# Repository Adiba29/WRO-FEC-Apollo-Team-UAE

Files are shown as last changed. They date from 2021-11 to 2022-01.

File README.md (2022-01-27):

# Engineering Materials

This repository contains engineering materials for **UAE's Team Apollo** participating  in in the WRO Future Engineers competition International Finals in the season 2021.

## Content

* `photos` contains 6 photos of the vehicle (from every side, from top and bottom)
* `schemes` contains one or several schematic diagrams in form of JPEG, PNG or PDF of the electromechanical components illustrating all the elements (electronic components and motors) used in the vehicle and how they connect to each other.
* `src` contains code of control software for all components which were programmed to participate in the competition
models is for the files for models used by 3D printers, laser cutting machines and CNC machines to produce the vehicle elements. If there is nothing to add to this location, the directory can be removed.
* `models` is for the files for models used by 3D printers, laser cutting machines and CNC machines to produce the vehicle elements. If there is nothing to add to this location, the directory can be removed.
* `other` is for other files which can be used to understand how to prepare the vehicle for the competition. It may include documentation how to connect to a SBC/SBM and upload files there, datasets, hardware specifications, communication protocols descriptions etc. If there is nothing to add to this location, the directory can be removed.

## Introduction

Team Apollo has designed a 4-wheel rear-wheel driven Arduino-PIXY2 based robotic car which primarily uses a lego chassis with a combination of 3D printed assets for WRO’s FEC. 
We aim to sustainably drive the future in order to efficiently aid the upcoming generation into AI-driven fields. 
For the build of the vehicle, we have used an **Arduino MEGA 2650 Microcontroller** in addition to its compatible sensors, such as the following:
* CMU Pixy Gen2 Camera
* HCSR04 Ultrasonic Sensors (5x)
* TCRT-5000 Analog Infrared Sensor (2x)
* MPU6050 Gyroscope Sensor
* L298n Motor Driver
* TowerPro SG90 9G Micro Servo
* 150 RPM BO Motor - Dual shaft
* Arduino Mini Breadboard
* 12V Lithium-ion Batteries (2x)
* 9V Battery, 2x SamBot Wheels (2x)
* 2x Lego Mini Wheels (2x)
* Lego Technic Kit

### Pixy 2 Camera:

A pixy 2 camera is used to identify and differentiate between traffic signs. Using the Pixy2 library, we first initiate the object pixy, and set up the pixy using ‘pixy.init()’ under void setup. Under the void loop, we write an initial ‘if’ statement activating the pixy with the statement ‘( pixy.ccc.getBlocks())’ under which we initialise a variable ‘dist’ which acts as a function for the following if statements.
A second ‘if’ statement is written ‘if (dist < 10)’ which only allows the pixy to detect objects at a distance less than 10cm away. Inside this, 2 if statements for each color of the traffic signs are written. The red block has been initialized as block[0], with the block signature as 1, if this particular block is detected, the servo is commanded to turn to 180 degrees for 1.5 seconds and then return to its original position. Similarly, the green block has been initialized as block[1], with the block signature as 2 and if detected the servo is commanded to turn to 90 degrees for 1.5 seconds and then return to its original position.
In addition to the detection of blocks, the pixy is also used for navigating through corners in the final round. Setting the orange and blue lines as two different signatures, we are able to turn the car. The mechanism starts with turning the servo to 60/160 degrees once the orange/blue line is detected (depending upon the driving direction) and turns until the second line(either orange or blue depending on the direction) is detected.
Motor Driver: We have employed the use of an L298n motor driver for controlling the speed and the direction of our real wheel drive DC motor. The code starts off by initializing our pins for direction(in1,2,3,4), speed(enA,enB)and a variable ‘sped’ to give a value of speed. Another variable called ‘count’ is initialized with the null value (int count;).Under the void setup all the pins are highlighted as output pins. Furthermore, under the void loop we specify the direction for our directional pins (eg: ‘digitalWrite (in1, HIGH);’) and the speed for our speed control pins as ‘sped’ (eg: ‘analogWrite (enA, sped);’ ). The motor is now functional and running with a speed of 50. To stop the motor at the correct position we specified an if statement under the void loop to check the value of count which if greater than or equal to 3(specifying the three laps) makes the speed controls of the motors 0(analogWrite (enA, 0);).

### Ultrasonic Sensor:

We have used the ultrasonic sensor to map out the boundaries of the game field in order to effectively map the borders and to make Apollo avoid crashing into one. We have initialized the trigger pin as the output and the echo pin as the input for the ultrasonic sensor. The trig pin is connected to pin number 12, the dt(distance) and echo pin are connected to pin number 11. The basic gist of the code turns the servo 90 degrees right/left if the ultrasonic sensor detects the presence of an object less than 10 cm away. The side to which the servo motor turns is determined by the ultrasonic sensor which gives out a signal in the presence of an object less than 10 cm away. For this purpose, we have employed the use of 5 ultrasonic sensors on our model, one on each side, 3 in the front, in which 2 are in the left and right center respectively and one is positioned dead-center. We initialize calc_dis as a variable to calculate the distance that is measured by the ultrasonic sensor. If the distance is less than 10 cm, Apollo instructs the servo to turn 90 degrees for a maximum duration of 1000 milliseconds and return to its original position within the same time frame. All 5 ultrasonic sensors work in harmony to maneuver the track. In addition to this, we also employ a counting mechanism which is used to stop the car in the optimum position after 3 laps have been completed.

### Servo:

We’ve used a TowerPro SG90 9G micro servo motor to help Apollo steer. It is attached to digital pin number 8 on the arduino. To custom fit the Arduino servo onto our lego chassis, we 3D printed a bracket that efficiently connects the servo bracket into the gear of the lego chassis that powers our ackermann steering mechanism. The servo uses 3 pins all connected to the arduino, one which acts as the unique servo data cable and the rest which is used primarily for power. The servo is connected to the lego gear using a 3D printed chassis which in-turn rotates two other gears connected to the axle connecting Apollo’s wheels. The servo turns these gears based on the Arduino's command as mentioned in the aforementioned sections. This is what forms the base of Apollos steering mechanism. The servo rotates at a couple of angles including 140,80,60,160 keeping 110 as the center.

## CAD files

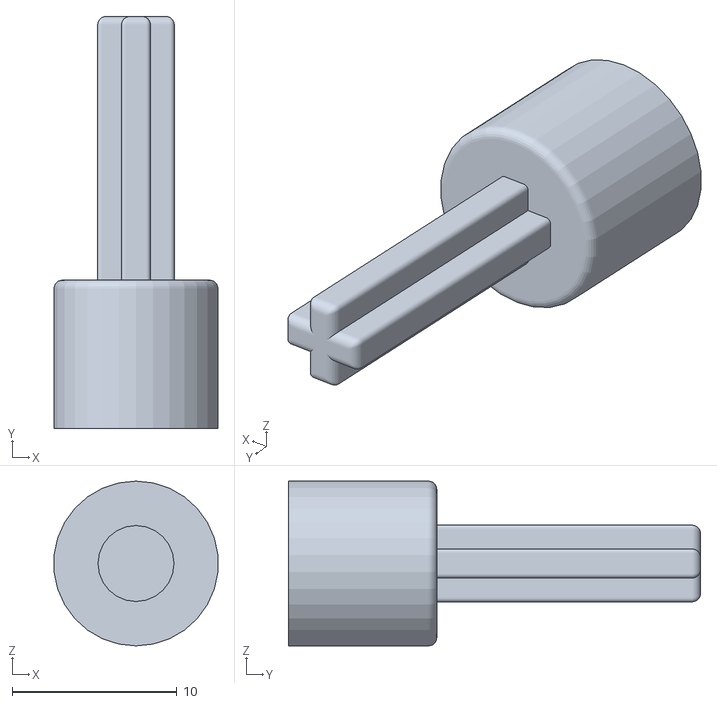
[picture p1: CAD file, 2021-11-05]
models/Metel Gear lego_axle_coupler v2.obj
9.95 x 25.0 x 10.0

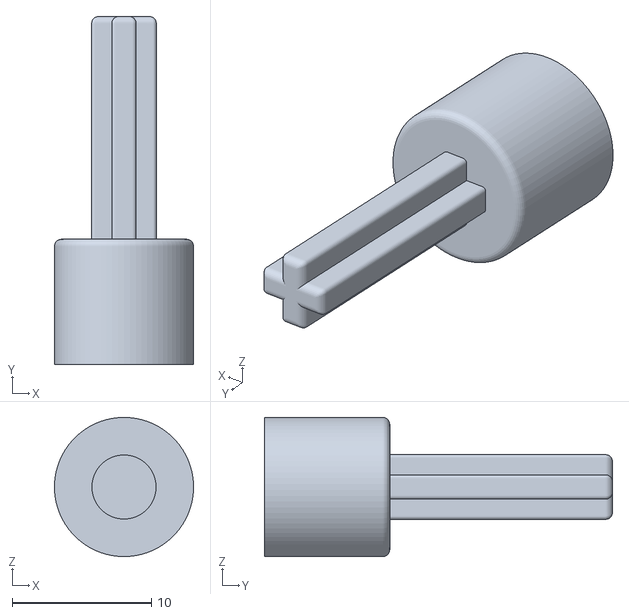
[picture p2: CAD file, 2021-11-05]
models/servo lego_axle_coupler v1.stl
9.99 x 25.0 x 10.0

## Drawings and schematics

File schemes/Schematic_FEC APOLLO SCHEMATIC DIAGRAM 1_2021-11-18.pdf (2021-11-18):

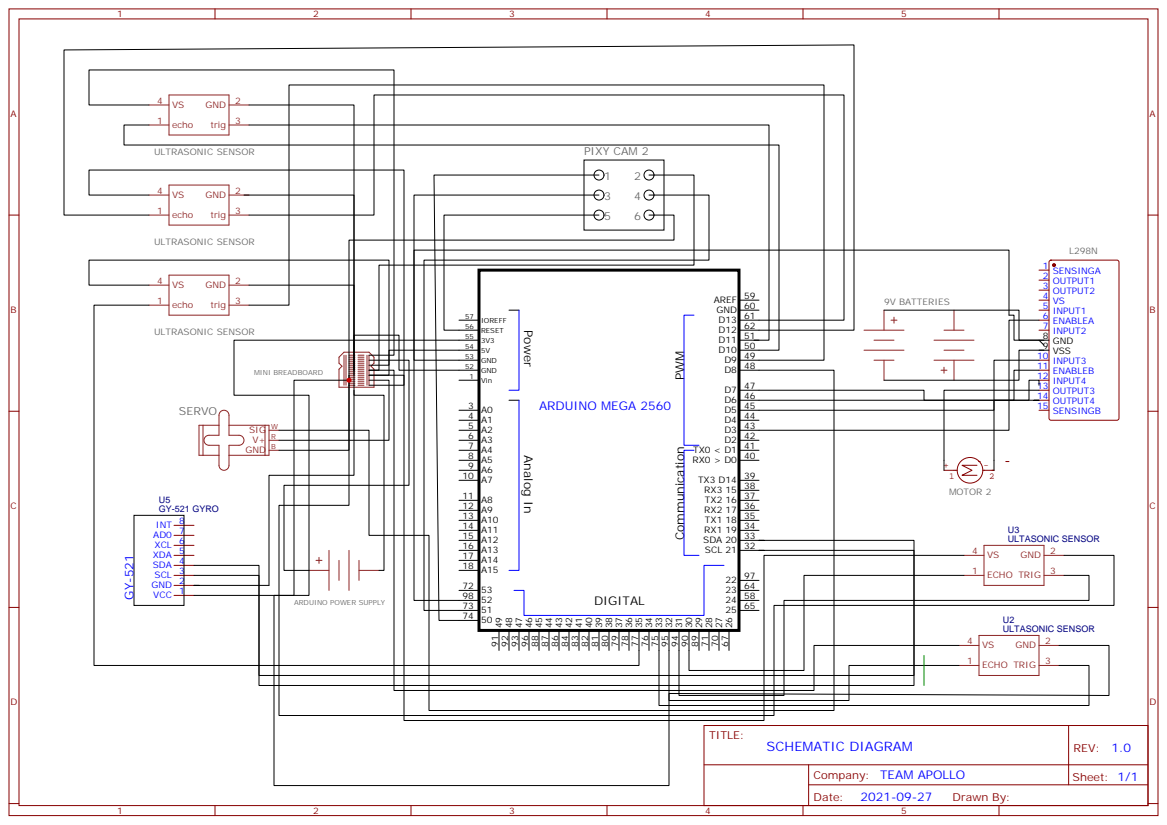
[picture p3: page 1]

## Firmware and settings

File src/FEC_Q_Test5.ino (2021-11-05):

#include <Pixy2.h>
#include <Servo.h>

Pixy2 pixy;
Servo myservo;

/////////CUSTOM DELAY VARIABLES//////
int period;
unsigned long time_now;

//////////MOTOR DRIVER PINS///////
int in1 = 24; 
int in2 = 25;
int enA = 2;

int in3 = 26;
int in4 = 27;
int enB = 3;
//////////////////////////////

//////////////////ULTRASONIC//////////////////////
#define echo1Pin 11
#define trig1Pin 10
#define echo2Pin 5
#define trig2Pin 4
#define echo3Pin 7
#define trig3Pin 6
#define echo4Pin 33
#define trig4Pin 32
#define echo5Pin 31
#define trig5Pin 30
long left_duration, leftUL_duration, right_duration, rightUL_duration, front_duration;
int left_dist, leftUL_dist, right_dist, rightUL_dist, front_dist;
/////////////////////////////////////////////////

int sped = 200;
int low_Sped = 190;
int counts = 0;
int num = 4;
int center_Pos = 110;
int flagg = 1;
float dist;

/////Push Button Variables////////
int pb = 40;
int pbState = 0;
int pbi = 0;

int loopcount = 0;

void setup() {


  Serial.begin(115200); //pixy baud rate

  pinMode(40, INPUT_PULLUP);
   
  pinMode(13, OUTPUT);
  pinMode(trig1Pin, OUTPUT);
  pinMode(echo1Pin, INPUT);
  
  pinMode(trig2Pin, OUTPUT);
  pinMode(echo2Pin, INPUT);
  
  pinMode(trig3Pin, OUTPUT);
  pinMode(echo3Pin, INPUT);

  
  
  myservo.attach(9);
  myservo.write(center_Pos);
  delay(500);
  myservo.write(60);
  delay(500);
  myservo.write(center_Pos);

  pinMode(enA, OUTPUT); //motor control components
  pinMode(enB, OUTPUT);
  pinMode(in1, OUTPUT);
  pinMode(in2, OUTPUT);
  pinMode(in3, OUTPUT);
  pinMode(in4, OUTPUT);

  pixy.init();          //setup pixy
  
}

void loop() {
//  delay(1000);
  ///////////PUSH BUTTON CODE//////////////
  pbState  = digitalRead(pb);
  if(pbState == LOW){
    pbi = 1;
    counts = 0;
    myservo.write(center_Pos);
    Serial.print("Button was pushed. i is ");
    Serial.println(pbi);
  }else {
    Serial.println("Button is LOW");
  }

  /////////////Push Button Start//////////////
  while(pbi == 1){
    pbi = 0;

   int starttime = millis();
   int endtime = starttime;
   
   while ((endtime - starttime) <= 500) // do this loop for up to 1000mS
   {
    // code here
    Serial.println("Moving speed initial stage...");
    
    digitalWrite(in1, LOW);
    digitalWrite(in2, HIGH);
    digitalWrite(in3, LOW);
    digitalWrite(in4, HIGH);
    digitalWrite(enA, HIGH);
    digitalWrite(enB, HIGH);

//    delay(500);
//    move_Straight();
      
//    loopcount = loopcount+1;
    endtime = millis();
   }

    /////////Main Code/////////
    while(counts < num){
//      delay(500);
      if(counts == num) {
        final_Stage();
        digitalWrite (enA, LOW);
        digitalWrite (enB, LOW);
      }else{ move_Straight();}
    
      get_Pings();
    
      Serial.print("The front Distance Is:");
      Serial.println(front_dist);
    
      Serial.print("right Distance: ");
      Serial.println(right_dist);

      Serial.print("left Distance: ");
      Serial.println(left_dist);  
      Serial.println(" ");

  
  
      Serial.println(" \n\n ");
      
      pixy.ccc.getBlocks();

      if(pixy.ccc.numBlocks){
        Serial.print("Distance to the nearest block detected is: ");
        pixy.ccc.blocks[0].print();
        Serial.println("");
          if(leftUL_dist < 11){
            myservo.write(60);
            Serial.println("vv Left ULTRAsonic detected and moving right, Left ultrasonic dist: ");
            Serial.println(leftUL_dist);
          }
          else if(rightUL_dist < 11){
            myservo.write(160);
            Serial.println("vv Right ULTRAsonic detected and moving left. Right ultrasonic dist: ");
            Serial.println(rightUL_dist);
          }

          else if(front_dist < 15 && front_dist != 0){
//            get_Pings();
            Serial.print("STOPPING, front dist is:___ ");
            Serial.println(front_dist);
            front_Stop();
          }
          
          else if(left_dist < 15 && left_dist != 0){
            Serial.println("VERY NEAR TO LEFT__");
//            get_Pings();
//            pixy.ccc.getBlocks();
            Serial.print("vv Turning right, left dist is: ");
            Serial.println(left_dist);
            myservo.write(80);
          }
          else if(left_dist > 20 && left_dist < 25){
            Serial.println("AWAY FPROM LEFT____");
//            get_Pings();
//            pixy.ccc.getBlocks();
            Serial.print("vv Turning left, left dist is: ");
            Serial.println(left_dist);
            myservo.write(140);
          }
          else if(left_dist >= 25){
            Serial.println("VERY VERY AWAY FPROM LEFT____");
//            get_Pings();
//            pixy.ccc.getBlocks();
            Serial.print("vv Turning left, left dist is: ");
            Serial.println(left_dist);
            myservo.write(120);
          }          
          
          else{
            myservo.write(center_Pos);
          }
   


//      Serial.println("Again print the detected blocks");
//      pixy.ccc.blocks[0].print();
//      Serial.println("");
    ////////ORANGE LINE TURN RIGHT////////
      if (pixy.ccc.blocks[0].m_signature == 3 && pixy.ccc.blocks[0].m_y > 180 && left_dist <=30 && left_dist != 0 ){  // && pixy.ccc.blocks[0].m_x < 55
        Serial.println("Detected ORANGE LINE, turning right");
//        delay(250);
        while((right_dist < 25 && right_dist != 0)||front_dist > 30){
          get_Pings();
          Serial.println("Keep going forward");
          Serial.println("Right dist      Front dist");
          Serial.println(String(right_dist)+"\t\t "+String(front_dist));
          Serial.println("\n");
        }
        while(right_dist > 16 || right_dist == 0){
          get_Pings();
          Serial.print("Turning right until blue detected or right distance is close. Rigth dist: ");
          Serial.println(right_dist);
          pixy.ccc.getBlocks();
          pixy.ccc.blocks[0].print();
          Serial.println("");
          myservo.write(60);
          //detect blue line to stop turning left
          if(pixy.ccc.blocks[0].m_signature == 4 && pixy.ccc.blocks[0].m_y > 180){  //chnanged from 160 t0 200 for m_x ... && pixy.ccc.blocks[0].m_x < 200
            pixy.ccc.blocks[0].print();
            Serial.println("Detected blue line. Will stop turning after the delay...");
//            delay(350);
            period = 350;
            time_now = millis();
            while(millis()< time_now + period){
              //wait approx. period ms
              if(rightUL_dist < 11){
                Serial.println("right ultrasonic detected during blue after turn delay before going straight");
                Serial.println("Right ultrasonic dist: " + String(rightUL_dist));
                break;
              }
            }
            break;
          }
          else if(front_dist < 6 and front_dist != 0){
            Serial.println("front dist too close. Stopping!!");
            Serial.print("STOPPINGgggggg, front dist is:___ ");
            Serial.println(front_dist);
            front_Stop();
            break;
          }
          else if(rightUL_dist < 11 ){
            Serial.println("Right ULTRAsonic detected too close. Stopping right turn immediately and TURNING LEFT! Right ultrasonic dist: ");
            Serial.println(rightUL_dist);
            myservo.write(160);
            period = 300;
            time_now = millis();
            while(millis() < time_now + period){
              //wait approx. period ms
            }
            break;
          }
        }
        counts++;
        Serial.print("Count incremented. count is: ");
        Serial.println(counts);
        if(counts == num){
          final_Stage();
        }else{
          myservo.write(center_Pos);
        }
      }
     }
      else {

        if(leftUL_dist < 11){
          myservo.write(60);
          Serial.println("Left ULTRAsonic detected and moving right, Left ultrasonic dist: ");
          Serial.println(leftUL_dist);
        }
        else if(rightUL_dist < 11){
          myservo.write(160);
          Serial.println("Right ULTRAsonic detected and moving left. Right ultrasonic dist: ");
          Serial.println(rightUL_dist);
        }

        else if(front_dist < 15 && front_dist != 0){
          Serial.print("Stopping, front dist is: ");
          Serial.println(front_dist);
          front_Stop();
        }
     
        else if(left_dist < 15 && left_dist != 0 && front_dist > 40){
          Serial.println("VERY NEAR TO LEFT");
          while(left_dist < 15 && front_dist > 40){
            get_Pings();
            pixy.ccc.getBlocks();
            Serial.print("Turning right, left dist is: ");
            Serial.println(left_dist);
            myservo.write(80);
            
          }
//          myservo.write(center_Pos);
        }
  
        else if(left_dist > 20 && left_dist < 25 && front_dist > 40){
          Serial.println("AWAY FROM LEFT");
          while(left_dist > 20 && front_dist > 40 && front_dist > 40){
            get_Pings();
            pixy.ccc.getBlocks();
            Serial.print("Turning left, left dist is: ");
            Serial.println(left_dist);
            myservo.write(130);  ////changed from 140 to 130 
            
          }
//          myservo.write(center_Pos);
        }

        else if (left_dist >= 25 && left_dist != 0 && front_dist > 40){
          Serial.println(" VERY VERY AWAY FROM LEFT");
          Serial.print("Turning left, left dist is: ");
          Serial.println(left_dist);
          while(left_dist >= 25 && left_dist < 50 && front_dist > 40){
            get_Pings();
            pixy.ccc.getBlocks();
            Serial.print("Turning left, left dist is: ");
            Serial.println(left_dist);
            myservo.write(120);  ////changed from 140 to 130
            
          }
        }
    
        else if(right_dist < 13 && right_dist != 0 && front_dist > 40){
          Serial.println("VERY NEAR TO RIGHT");
          while(right_dist < 15 && front_dist > 40){
            get_Pings();
            pixy.ccc.getBlocks();
            Serial.print("Turning left, right dist is: ");
            Serial.println(right_dist);
            myservo.write(140);
          }
//          myservo.write(center_Pos);
        }     
        
        else{
          myservo.write(center_Pos);
          Serial.println("Nothing detected..");
        }

        
      }
    }
  }
  
  analogWrite(enA, LOW);
  analogWrite(enB, LOW);
  
}


void move_Straight(){
  
  analogWrite(enA, sped);
  analogWrite(enB, sped);
  
  digitalWrite(in1, LOW);
  digitalWrite(in2, HIGH);
  digitalWrite(in3, LOW);
  digitalWrite(in4, HIGH);
 //delay(10);
}

void move_Reverse(){
  
  analogWrite(enA, sped);
  analogWrite(enB, sped);
  
  digitalWrite(in1, HIGH);
  digitalWrite(in2, LOW);
  digitalWrite(in3, HIGH);
  digitalWrite(in4, LOW);
 //delay(10);
}

void move_Slow(){
  
  analogWrite(enA, low_Sped);
  analogWrite(enB, low_Sped);
  
  digitalWrite(in1, LOW);
  digitalWrite(in2, HIGH);
  digitalWrite(in3, LOW);
  digitalWrite(in4, HIGH);

}

int final_Stage(){
  
  int starttime, endtime, loopcount;
  starttime = millis();
  endtime = starttime;
  while ((endtime - starttime) <=2000) // do this loop for up to 1000mS
  {
  // code here
  get_Pings();
    if (left_dist < 15 && left_dist != 0) {
      myservo.write(60);
    }
    else if (right_dist < 15 && right_dist != 0) {
      myservo.write(160);
    }
    else{
      myservo.write(center_Pos);
    }
      
    loopcount = loopcount+1;
    endtime = millis();
  }
  Serial.write(center_Pos);
  move_Reverse();
//  delay(500);
  period = 500;
  time_now = millis();
  while(millis()< time_now + period){
    //wait approx. period ms
  }
  //serial.print (loopcount,DEC);
}

void get_Pings(){
//    Serial.println("Beginning get_Pings() funciton");
    digitalWrite(trig1Pin, LOW);
    delayMicroseconds(2);
//    for(volatile int i = 0; i<1; i++){
//      asm(""); //...this is delay for 1.94 seconds
//    } 
    digitalWrite(trig1Pin, HIGH);
    delayMicroseconds(10);
//    for(volatile int i = 0; i<8; i++){
//    //This is delay for 10.25 microseconds
//    }
    digitalWrite(trig1Pin, LOW);
    left_duration = pulseIn(echo1Pin, HIGH);
    left_dist = left_duration * 0.034 / 2;
    if (left_dist > 400){
      left_dist = 0;
    }
  
    digitalWrite(trig2Pin, LOW);
    delayMicroseconds(2);
    digitalWrite(trig2Pin, HIGH);
    delayMicroseconds(10);
    digitalWrite(trig2Pin, LOW);
    right_duration = pulseIn(echo2Pin, HIGH);
    right_dist = right_duration * 0.034 / 2;
    if(right_dist > 400){
      right_dist = 0;
    }
  
    digitalWrite(trig3Pin, LOW);
    delayMicroseconds(2);
    digitalWrite(trig3Pin, HIGH);
    delayMicroseconds(10);
    digitalWrite(trig3Pin, LOW);
    front_duration = pulseIn(echo3Pin, HIGH);
    front_dist = front_duration * 0.034 / 2;
    if(front_dist > 400){
      front_dist = 0;
    }

    digitalWrite(trig4Pin, LOW);
    delayMicroseconds(2);
    digitalWrite(trig4Pin, HIGH);
    delayMicroseconds(10);
    digitalWrite(trig4Pin, LOW);
    leftUL_duration = pulseIn(echo4Pin, HIGH);
    leftUL_dist = leftUL_duration * 0.034 / 2;
    if(leftUL_dist > 400){
      leftUL_dist = 0;
    }
    
    digitalWrite(trig4Pin, LOW);
    delayMicroseconds(2);
    digitalWrite(trig4Pin, HIGH);
    delayMicroseconds(10);
    digitalWrite(trig4Pin, LOW);
    rightUL_duration = pulseIn(echo4Pin, HIGH);
    rightUL_dist = rightUL_duration * 0.034 / 2;
    if(rightUL_dist > 400){
      rightUL_dist = 0;
    }
    

//    Serial.println("Ending get_Pings() function");

    return left_dist, right_dist, front_dist, leftUL_dist, rightUL_dist;
}

void front_Stop(){
  get_Pings();
  //    pixy.ccc.getBlocks();
  //    Serial.print("Front obstacle detect, Stopping the car.... ");
  //    Serial.print("   front dist: ");
  //    Serial.println(front_dist);
        counts = num;
  //    myservo.write(60);
        move_Reverse();
//        delay(500);
        period = 500;
        time_now = millis();
        while(millis()< time_now + period){
          //wait approx. period ms
        }
  //    myservo.write(center_Pos);
}

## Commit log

2021-11-05 Create Vehicle Schematic Diagram
2021-11-05 Create Metel Gear lego_axle_coupler v2.obj
    [Metel Gear lego_axle_coupler v2.obj]
